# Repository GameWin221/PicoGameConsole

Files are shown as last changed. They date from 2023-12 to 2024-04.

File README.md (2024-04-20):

# Shamino Console
My own game console powered by Raspberry Pi Pico and ST7735 LCD display.

### Software Design
The console framework is made to be **elegant**, **readable** and as **performant** as possible. It is written in C++ only for some convenience features and most of it is almost pure embedded-style C. Thanks to the functional and modular code structure it is easy to port it for other platforms.

You can make your own game just by declaring a new `GameInfo` inside `games_list.hpp` file and defining its functions inside other `.cpp` file. (Look at other example games provided in the repository)

### Hardware Design
The new improved version of the "Shamino Console" now features a custom PCB. This greatly improves the general quality of the console. It just looks and feels better now :)

There will be a 3D printed casing for it soon.

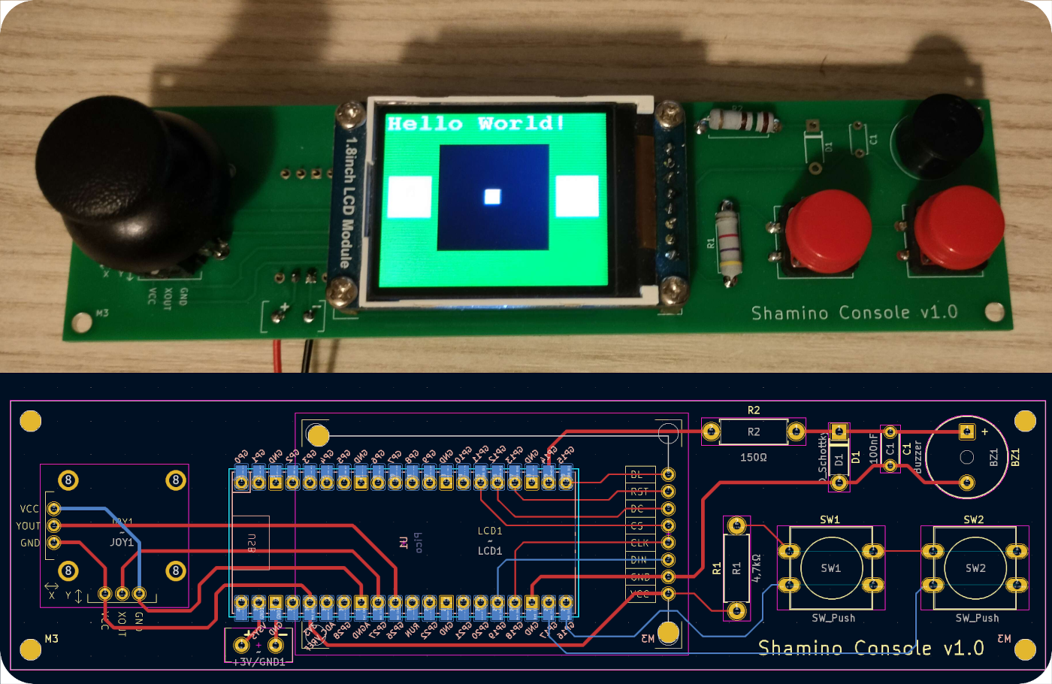
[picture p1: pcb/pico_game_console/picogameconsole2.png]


To see the old version, look inside the `/old_design` directory.

### Required componnts:
- [Raspberry Pi Pico (W)](https://www.raspberrypi.com/products/raspberry-pi-pico/)

- [Waveshare ST7735 1.8" LCD](https://www.waveshare.com/wiki/1.8inch_LCD_Module)

- [Generic Thumb Joystick](https://botland.store/joystick/1942-thumb-joystick-5904422356231.html)

- 2x [12mm x 12mm Tact Switches](https://botland.store/tact-switch/3663-tact-switch-12x12mm-with-cap-red-mushroom-5pcs-5904422307486.html)

- [Female Connectors for Raspberry Pi Pico](https://botland.store/raspberry-pi-pico-accessories/18863-set-of-female-connectors-for-raspberry-pi-pico-5904422328528.html)

- [5V 12mm Passive Buzzer](https://botland.store/buzzers-sound-generators/18290-buzzer-without-generator-5v-1mm-tht-5904422366025.html)

- ~47Ω Resistor

- ~4,7kΩ Resistor

- [1x8 Goldpin connector](https://botland.store/connectors-goldpin/20031-straight-goldpin-1x40-connector-with-254mm-pitch-black-10pcs-justpi-5904422329198.html)

- (Optional) 2x 5mm M3 Screw to mount the LCD

- 4x 10mm M3 Screws to mount the PCB to the 3D printed casing.

- [Battery Holder for 2x AA batteries **with a power switch** (3x AA batteries will work fine too)](https://botland.store/battery-holders/738-battery-holder-for-2-aa-r6-batteries-with-cover-and-switch-5904422329617.html)

# How to compile? 
### Prerequisites
- [Pico SDK](https://github.com/raspberrypi/pico-sdk) (St the `PICO_SDK_PATH` enviromental variable)
- [ARM Toolchain](https://developer.arm.com/downloads/-/arm-gnu-toolchain-downloads) (Set the `PICO_TOOLCHAIN_PATH` enviromental variable)
- [CMake](https://cmake.org/) (Add to path)
- [MinGW](https://winlibs.com/) or other C++ compiler (Add to path)

### Commands (Using MinGW):
1. `mkdir build && cd build`
2. `cmake -G "MinGW Makefiles" ..`
3. `make` or `mingw32-make`
4. If everything compiled successfully - copy the `GameOnConsole.uf2` file to your Pico

On Windows you can use the `run.bat` script (You will most likely need to specify the target drive which is your Pico)

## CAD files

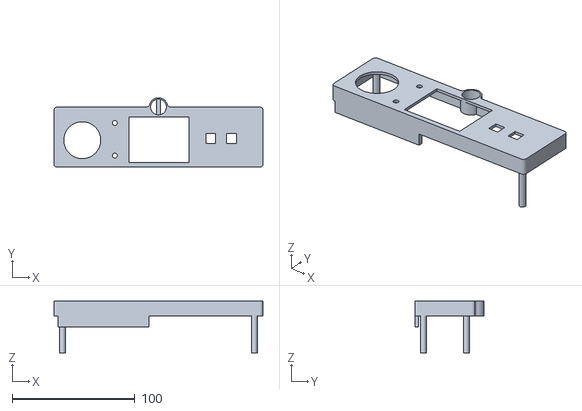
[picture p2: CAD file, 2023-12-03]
UpperCover.stl
170.0 x 56.5 x 42.0

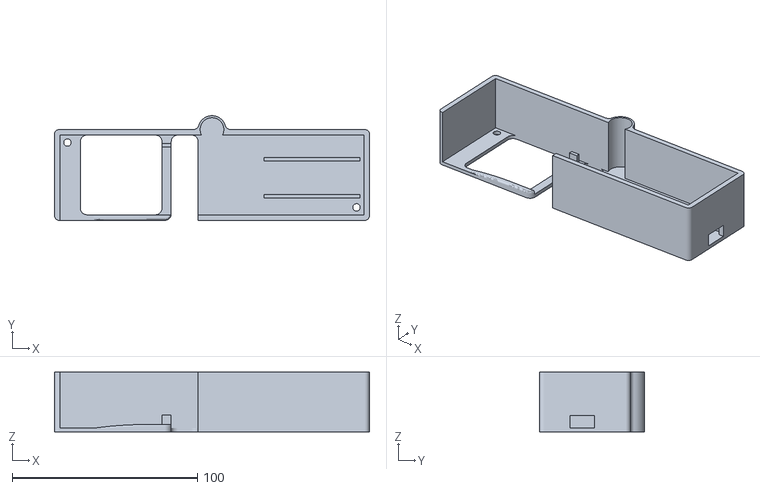
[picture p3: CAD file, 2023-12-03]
BottomCover.stl
170.0 x 56.5 x 32.3

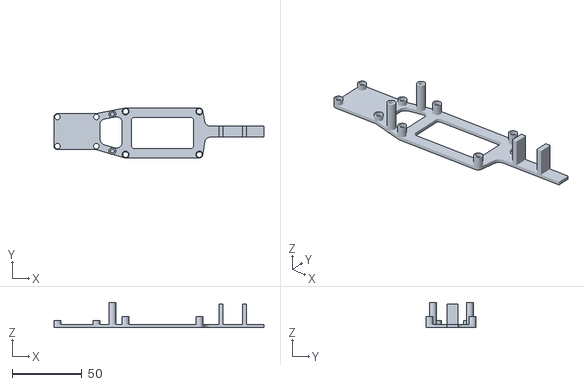
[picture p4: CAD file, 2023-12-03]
Holder.stl
151.0 x 36.0 x 18.0

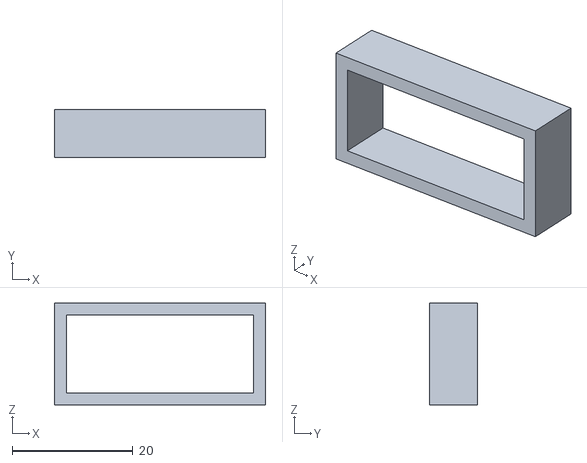
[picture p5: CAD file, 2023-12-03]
PushBlock.stl
35.0 x 8.00 x 16.9

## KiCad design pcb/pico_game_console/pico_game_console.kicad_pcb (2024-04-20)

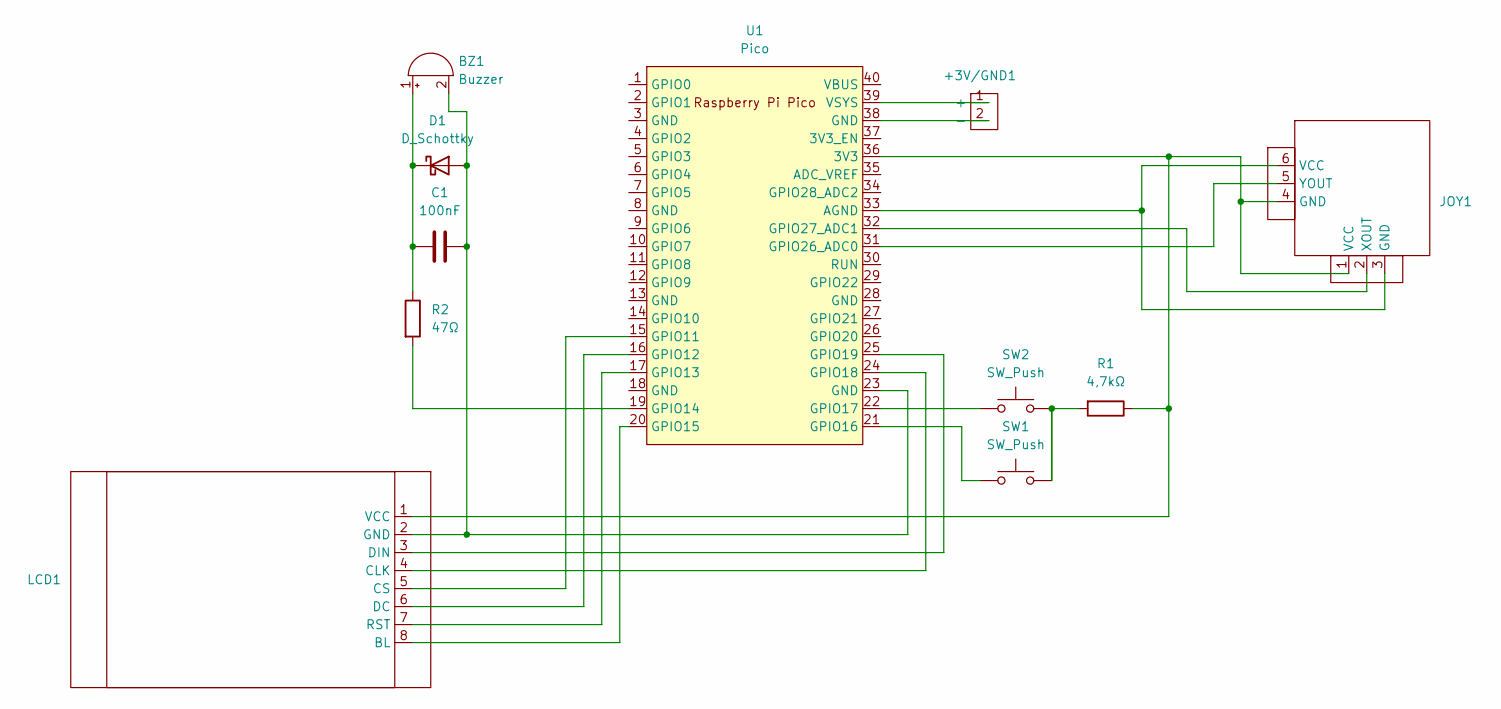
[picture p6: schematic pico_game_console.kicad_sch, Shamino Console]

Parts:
+3V/GND1: PowerPins
BZ1: Buzzer; Buzzer_12x9.5RM7.6
C1: 100nF; C_Disc_D5.0mm_W2.5mm_P5.00mm
D1: D_Schottky; D_DO-41_SOD81_P7.62mm_Horizontal
JOY1: Thumb Joystick
LCD1: 1.8Inch_ST7735
R1: 4,7kΩ; R_Axial_DIN0411_L9.9mm_D3.6mm_P12.70mm_Horizontal
R2: 47Ω; R_Axial_DIN0411_L9.9mm_D3.6mm_P12.70mm_Horizontal
SW1, SW2: SW_Push; SW_PUSH-12mm
U1: Pico; RPi_Pico_SMD_TH

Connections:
unnamed: +3V/GND1.1 (+), U1.39 (VSYS)
unnamed: +3V/GND1.2 (-), U1.38 (GND)
unnamed: BZ1.1 (+), C1.1, D1.1 (K), R2.1
unnamed: BZ1.2 (-), C1.2, D1.2 (A), LCD1.2 (GND), U1.23 (GND)
unnamed: JOY1.2 (XOUT), U1.32 (GPIO27_ADC1)
unnamed: JOY1.5 (YOUT), U1.31 (GPIO26_ADC0)
unnamed: LCD1.8 (BL), U1.20 (GPIO15)
unnamed: LCD1.4 (CLK), U1.24 (GPIO18)
unnamed: LCD1.5 (CS), U1.15 (GPIO11)
unnamed: LCD1.6 (DC), U1.16 (GPIO12)
unnamed: LCD1.3 (DIN), U1.25 (GPIO19)
unnamed: LCD1.7 (RST), U1.17 (GPIO13)
unnamed: JOY1.1 (VCC), JOY1.4 (GND), LCD1.1 (VCC), R1.1, U1.36 (3V3)
unnamed: R1.2, SW1.1, SW2.1
unnamed: JOY1.3 (GND), JOY1.6 (VCC), U1.33 (AGND)
unnamed: R2.2, U1.19 (GPIO14)
unnamed: SW1.2, U1.21 (GPIO16)
unnamed: SW2.2, U1.22 (GPIO17)

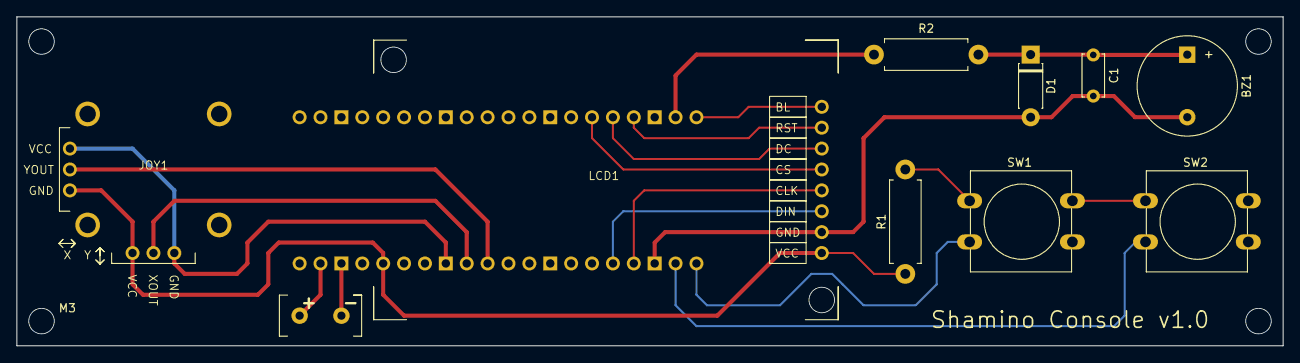
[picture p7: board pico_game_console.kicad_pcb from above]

Board: 2 copper layers, 154.0 x 40.0 mm, 11 parts (1 on the bottom side), 18 nets.

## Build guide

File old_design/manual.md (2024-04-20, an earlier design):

# How to assemble?

### Required Components:
- [Raspberry Pi Pico](https://www.raspberrypi.com/products/raspberry-pi-pico/)

- [Waveshare ST7735 1.8" LCD](https://www.waveshare.com/wiki/1.8inch_LCD_Module)

- [Iduino ST1079 Joystick Module](https://botland.store/joystick/4093-thumb-joystick-with-v2-button-module-with-a-5903351241441.html)

- 2x [6x6mm / 4,3mm Tact Switches](https://botland.store/tact-switch/377-tact-switch-6x6mm-43mm-dip-5-pcs-5904422307622.html)

- [5V Active Buzzer](https://botland.store/buzzers-sound-generators/786-active-buzzer-with-generator-5v-12mm-tht-5904422366940.html)

- 6x M3 **Exactly 10mm** Screws

- 2x M3 Hex Nuts

- 2x M3 10-30mm Screws

- 2x AA Battery Holder

- 2x AA Battery

### Component Connection Diagram:
Look at the `wiring_diagram.svg` file provided in the repository for better quality.



*The diagram was made with the EasyEDA editor.*

### 3D Printed Case:
Fusion 360 Project Link: https://a360.co/3T8A1c6 or use the .stl files provided in the repository.

### Required Tools:
- Soldering iron
- Glue that works on 3D printed plasic
- Hex screwdriver that fits M3 screws

### Assembly Instructions:
- Glue `PushBlock.stl` on the bottom side under `Holder.stl`'s tact switch poles. (This will ensure that Raspberry Pi Pico doesn't move inside.
- Glue the tact switches to the tact switch poles on `Holder.stl`.
- Screw the LCD display and the joystick module to `Holder.stl`.
- Screw `UpperCover.stl` to `Holder.stl`.
- Put in the buzzer (and glue it in if necessary) in the hole on the top of `UpperCover.stl`.
- Connect all of the components as shown on the component connection diagram.
- Put the Raspberry Pi Pico upside down with its micro-usb port facing the micro-usb hole in the 3D printed case.
- Screw `UpperCover.stl` and `BottomCover.stl` together. (Make sure no wires get damaged)

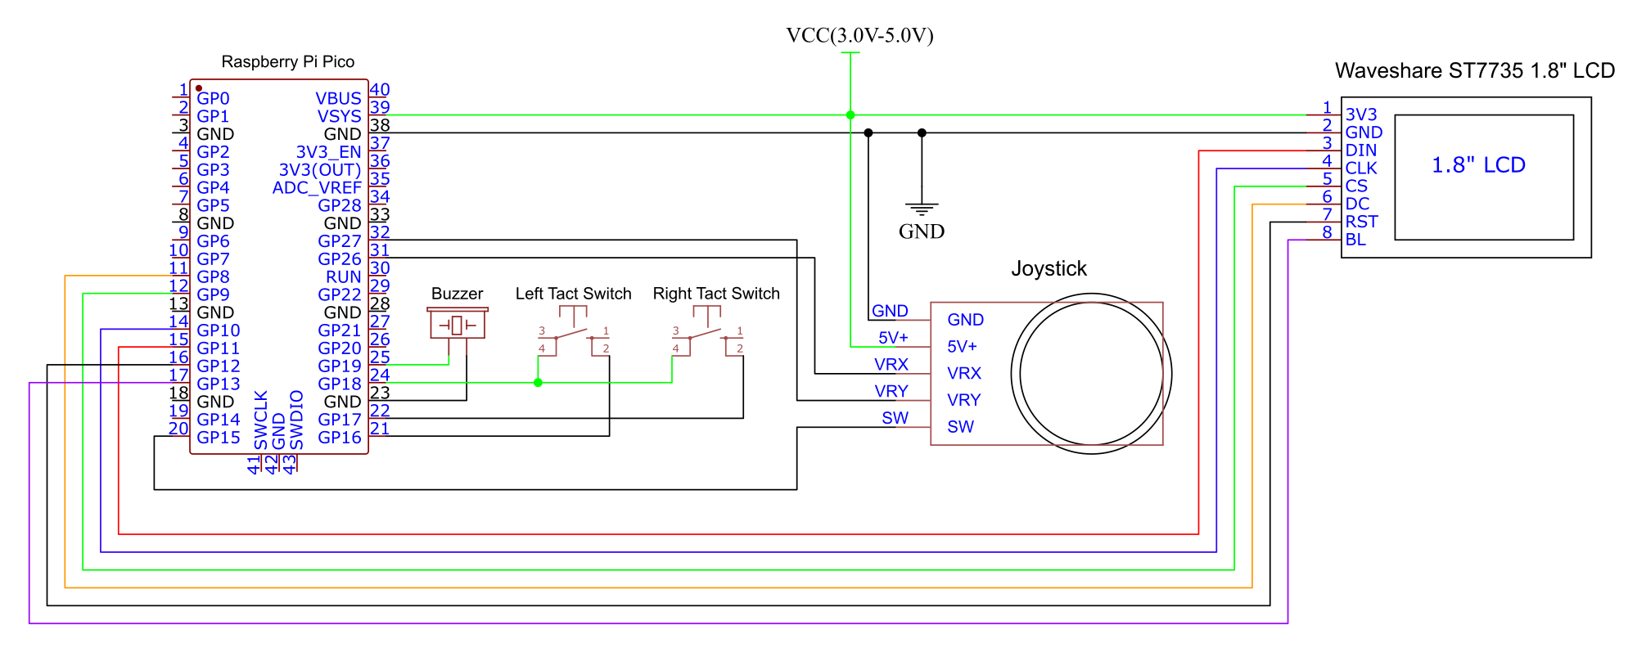
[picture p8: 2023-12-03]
wiring_diagram.png

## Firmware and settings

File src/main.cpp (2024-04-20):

#include "lcd_fonts/lcd_fonts.hpp"
#include "console_lcd.hpp"
#include "console_draw.hpp"
#include "console_core.hpp"
#include "console_timing.hpp"
#include "console_audio.hpp"
#include "console_input.hpp"

#include "games/games_list.hpp"

/// Potential optimisations:
// Second core for SPI canvas transfer
// Update only a part of the screen (set Windows before draw)
// Use uint16_fast_t

/// TODO:
// Make my own font
// Fix the bottom line (visible in doom game)
// README
// Improve console_audio module to use actual hz values
// Improve console_lcd module to sync with horizontal and vertical lines signals (pseudo vsync)

int main() {
	ConsoleInput input{};
	ConsoleTiming timing{};
	
	console_lcd_init();
	console_timing_init();
	console_input_init();
	console_audio_init();
	
	console_core_load_game(game_menu_info);

	while(true) {
		console_input_poll(&input);
		console_timing_update(&timing);
		console_core_update_game(input, timing);
		console_lcd_display((const uint8_t*)console_draw_get_canvas());
	}
}

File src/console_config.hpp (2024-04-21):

#ifndef CONSOLE_CONFIG_HPP
#define CONSOLE_CONFIG_HPP

/// console_audio ///
#define BUZZER_PIN 14

#define PWM_WRAP 10000
#define PWM_DUTY (PWM_WRAP / 2)

/// console_input ///
#define JOYSTICK_XAXIS_PIN 27
#define JOYSTICK_YAXIS_PIN 26

#define BUTTON_LEFT_PIN 16
#define BUTTON_RIGHT_PIN 17

/// console_lcd ///
#define LCD_DIN 19
#define LCD_CLK 18
#define LCD_CS  11
#define LCD_DC  12 
#define LCD_RST 13
#define LCD_BL  15

// Sending data at 65.536MHz - the max possible spi frequency
#define SPI_FREQ 65536000
#define SPI_CHANNEL spi0

#define LCD_CMD_SLEEP_IN 0x11
#define LCD_CMD_SLEEP_OUT 0x11
#define LCD_CMD_INVERSION_ON 0x21
#define LCD_CMD_INVERSION_OFF 0x20
#define LCD_CMD_GAMMA_SET 0x26
#define LCD_CMD_DISPLAY_ON 0x29
#define LCD_CMD_DISPLAY_OFF 0x28
#define LCD_CMD_COLUMN_ADDR_SET 0x2a
#define LCD_CMD_ROW_ADDR_SET 0x2b
#define LCD_CMD_MEMORY_WRITE 0x2c
#define LCD_CMD_TEARING_ON 0x35
#define LCD_CMD_TEARING_OFF 0x34
#define LCD_CMD_MEM_ACCESS_CTL 0x36
#define LCD_CMD_COLOR_MODE 0x3a

#define LCD_SCAN_HORIZONTAL 0x00
#define LCD_SCAN_VERTICAL 0x01

#define LCD_SCAN_DIRECTION LCD_SCAN_HORIZONTAL

#if LCD_SCAN_DIRECTION == LCD_SCAN_HORIZONTAL
    #define LCD_HEIGHT 128
    #define LCD_WIDTH 160
#elif LCD_SCAN_DIRECTION == LCD_SCAN_VERTICAL
    #define LCD_HEIGHT 160
    #define LCD_WIDTH 128
#endif

#define LCD_GAMMA_CURVE_2_2 0x01
#define LCD_GAMMA_CURVE_1_8 0x02
#define LCD_GAMMA_CURVE_2_5 0x04
#define LCD_GAMMA_CURVE_2_0 0x08
#define LCD_GAMMA_CURVE_DEFAULT LCD_GAMMA_CURVE_2_2

#define LCD_COLOR_MODE_4R4G4B 0x03
#define LCD_COLOR_MODE_5R6G5B 0x05
#define LCD_COLOR_MODE_6R6G6B 0x06
#define LCD_COLOR_MODE_DEFAULT LCD_COLOR_MODE_5R6G5B

#define LCD_INVERSION_DEFAULT false

#define LCD_TEARING_V_BLANK 0x00
#define LCD_TEARING_VH_BLANK 0x01
#define LCD_TEARING_OFF 0x02
#define LCD_TEARING_DEFAULT LCD_TEARING_OFF

#define LCD_MEM_CTL_MY  (1<<7) // Row Address Order        (0 = Left to right, 1 = Right to left)
#define LCD_MEM_CTL_MX  (1<<6) // Column Address Order     (0 = Bottom to top, 1 = Top to bottom)
#define LCD_MEM_CTL_MV  (1<<5) // Row / Column Exchange    (0 = (X: Column, Y: Row), 1 = (X: Row, Y: Column))
#define LCD_MEM_CTL_ML  (1<<4) // Vertical Refresh Order   (0 = Top to bottom, 1 = Bottom to top)
#define LCD_MEM_CTL_BGR (1<<3) // RGB or BGR Order         (0 = RGB, 1 = BGR)
#define LCD_MEM_CTL_MH  (1<<2) // Horizontal Refresh Order (0 = Left to right, 1 = Right to left)
#define LCD_MEM_CTL_DEFAULT 0

#endif

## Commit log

2023-11-30 Project structure and base framework.
2023-12-03 Initial 3D prints and wiring diagram.
    [BottomCover.stl, Holder.stl, PushBlock.stl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]
2023-12-16 Correct frequency based audio
    [console_audio.cpp, console_input.cpp, console_lcd.cpp]
2024-04-20 New PCB
    [pico_game_console-B_Cu.gbr, pico_game_console-B_Mask.gbr, pico_game_console-B_Paste.gbr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]
2024-04-20 Update to the new version
    [BottomCover.stl, Holder.stl, PushBlock.stl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]
